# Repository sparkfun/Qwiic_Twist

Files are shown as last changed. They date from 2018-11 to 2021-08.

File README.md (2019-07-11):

SparkFun Qwiic Twist 
===========================================================

SparkFun Qwiic Twist

[*SparkFun Qwiic Twist (DEV-15083)*](https://www.sparkfun.com/products/15083)

Sometimes you just need a volume knob. The Qwiic Twist is a digital RGB encoder. What does that mean? The Twist takes care of all the various interrupts, switches, PWM'ing of LEDs and presents all those features over an easy-to-use I<sup>2</sup>C interface. The Qwiic Twist was designed to get rid of the large mass of wires that are needed to implement an RGB encoder in a breadboard. Stop messing around with interrupt debugging and get back to your project!

One rotation in the clockwise direction increases the overall count by 24 and -24 in the counter clockwise direction. The number of 'ticks' or steps the user has turned the knob are transmitted over I2C. Additionally, the red, green, and blue LEDs are all set via software commands and can be digitally mixed to achieve over 16 million colors. 

We designed Qwiic Twist with an indent encoder which gives the user a great 'clicky' feel. Additionally, the encoder has a built in button so the user can select an GUI menu or element by pressing on the encoder.

The I2C address of Qwiic Twist is software configurable which means you can hookup over 100 on a single I2C bus!

Repository Contents
-------------------

* **/Documents** - Datasheet for the Qwiic Twist 
* **/Firmware/Qwiic_Twist** - Firmware for the Qwiic Twist
* **Hardware** - .brd and .sch for Qwiic Twist 

Documentation
--------------
* **[Qwiic Twist Hookup Guide](https://learn.sparkfun.com/tutorials/qwiic-twist-hookup-guide)** - Hookup guide for the Qwiic Twist
* **[Qwiic Twist Arduino Library](https://github.com/sparkfun/SparkFun_Qwiic_Twist_Arduino_Library)** - Arduino Library for the Qwiic Twist
* **[Installing an Arduino Library Guide](https://learn.sparkfun.com/tutorials/installing-an-arduino-library)** - Basic information on how to install an Arduino library.
* **[Product Repository](https://github.com/sparkfun/Qwiic_Twist)** - Main repository (including hardware files)

License Information
-------------------

This product is _**open source**_! 

Please review the LICENSE.md file for license information. 

If you have any questions or concerns on licensing, please visit the [SparkFun Forum](https://forum.sparkfun.com/index.php) and post a topic. For more general questions related to our qwiic system, please visit this section of the forum: [SparkFun Forums: QWIIC SYSTEMS](https://forum.sparkfun.com/viewforum.php?f=105)

Please use, reuse, and modify these files as you see fit. Please maintain attribution to SparkFun Electronics and release any derivative under the same license.

Distributed as-is; no warranty is given.
- Your friends at SparkFun.

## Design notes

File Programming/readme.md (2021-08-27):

Programming ATtiny84x in Circuit
===========================================================

The Qwiic Twist uses an ATtiny84A that must be programmed with firmware. This is done with spring pins aka Pogo Pins and an AVR programmer of your choice. We've had success with using an [Arduino as the ISP programmer](https://www.arduino.cc/en/Tutorial/BuiltInExamples/ArduinoISP) but we use the [Tiny AVR Programmer](https://www.sparkfun.com/products/11801) for day to day work.

1) Get the Tiny AVR Programmer and the [necessary drivers](https://learn.sparkfun.com/tutorials/tiny-avr-programmer-hookup-guide#driver-installation) installed. 
2) Clear the VCC solder jumper from the Tiny AVR Programmer. This jumper is closed by default and will power the target at 5V. While 5V will not harm the ATtiny targets, but many Qwiic boards have 3.3V sensitive sensors and peripherals so it's best to power the target through a Qwiic cable.
3) Solder 6-pin [female header](https://www.sparkfun.com/products/115) to the bottom of the programmer
4) Assemble the [SparkFun ISP Pogo Adapter](https://www.sparkfun.com/products/11591)
5) Attach the pogo adapter to the bottom of the programmer.

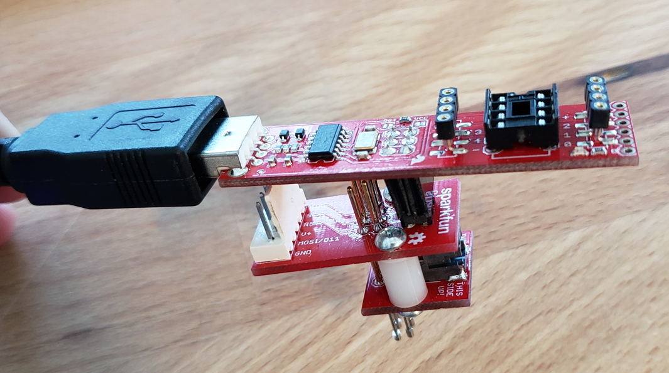
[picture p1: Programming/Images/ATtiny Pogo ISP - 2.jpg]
Programming ISP via Pogo Pins on ATtiny84A


6) Identify and mark pin 1 on the bottom of the adapter. You'll need to know where pin 1 is to align it on the target ISP holes.

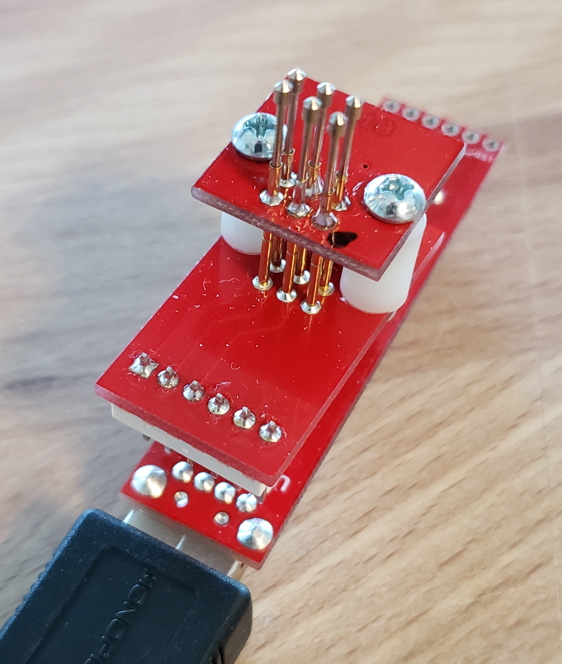
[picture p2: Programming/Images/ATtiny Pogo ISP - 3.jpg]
Programming ISP via Pogo Pins on ATtiny84A


7) Attach Tiny AVR Programmer to a USB extension cable to allow free movement of the programmer. Confirm that avrdude can see the programmer.
8) Connect the target device to a development board using a Qwiic cable so that it is powered.
9) Download the contents of the 'Programming' folder so that you have **avrdude.exe**, **avrdude.conf**, and **program_qwiic_twist.bat** in a folder.
9) Open a command line, navigate to 'program_qwiic_twist.bat' and run. It should fail because no ATtiny was detected. If it failed because an attinyusb was not found then you may need to troubleshoot your Tiny AVR Programmer and/or edit the batch file to match your programmer type.
10) Press and hold the pogo pins against the 6 exposed pins on the target. Your mark on the pogo pins should match with the small white silkscreen on the ISP on the target. You may need to wiggle the Pogo adapter until you hear all 6 pins seat into the ISP footprint.

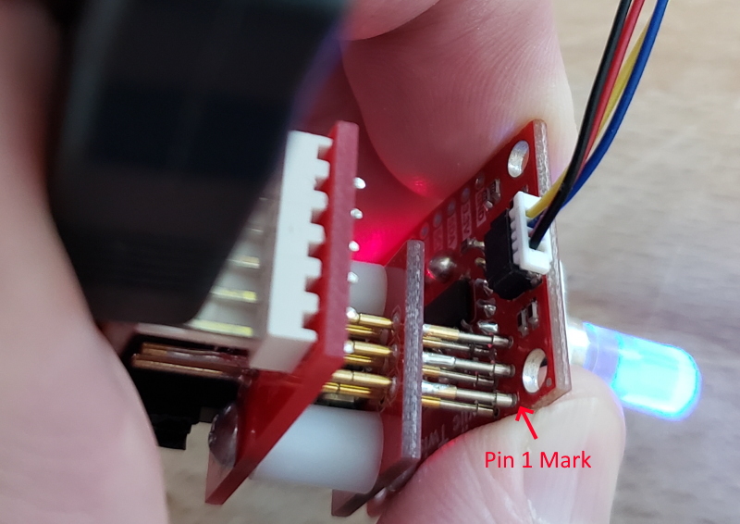
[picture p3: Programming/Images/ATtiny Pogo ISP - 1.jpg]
Programming ISP via Pogo Pins on ATtiny84A


11) Press enter with your free hand to begin programming.
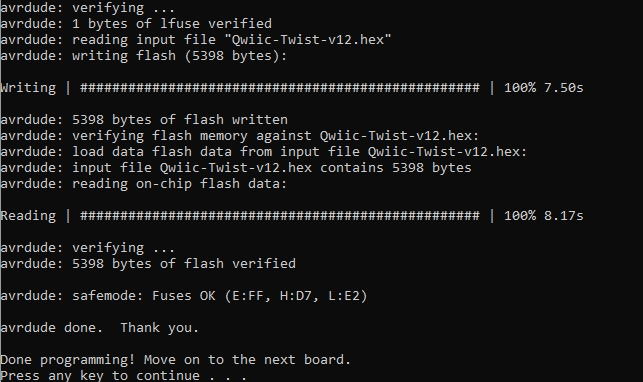
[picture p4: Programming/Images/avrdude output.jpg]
Programming ISP via Pogo Pins on ATtiny84A


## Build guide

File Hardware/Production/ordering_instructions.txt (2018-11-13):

panel size, 76x195mm
PCB thickness, 1.6mm
number of layers, 2
soldermask color, Red
silkscreen color, White
oz copper, 1oz
finish, HASL lead free
stencils, top+bottom
pcs per panel, 14

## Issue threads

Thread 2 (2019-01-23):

Change INT to a state machine

nseidle, 2019-01-23:
The interrupt pin toggles in bad ways.

When a user reads any bytes from Twist it causes the INT pin to go to high impedance, indicating the clearing of interrupts. However, back in the main loop the interrupt bits are still set so the INT pin is then set back to low. This looks like a toggle INT pin to the user.

Better to go to a state machine such as the one used on Qwiic MP3 Trigger.

nseidle, 2019-07-01:
Fixed in v1.2 of firmware now pushed to production.

Closed 2019-07-01.

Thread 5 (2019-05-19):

Schematic has wrong I2C address listed

EmbeddedMan, 2019-05-19:
The current version of the Eagle Schematic for this product lists it's I2C address as 0x5B (default). However, it does not respond to 0x5B out of the box.

Instead, if you look at the 'register map' here : https://cdn.sparkfun.com/r/600-600/assets/5/3/d/5/6/RegisterMap.jpg (linked to from the SparkFun product page for this product) it says the I2C address is 0x3F, which the board does respond to out of the box. (And the line in the firmware const byte I2C_ADDRESS_DEFAULT = 0x3F; also reflects this address.)

Either the schematic should be updated to reflect the firmware and register map, or the register map and firmware should be updated to reflect the schematic.

nseidle, 2019-05-20:
Sorry! My fault. Schematic text was pulled in from previous product. SCH on repo has been fixed. PDF on product page has been fixed.

Default I2C is 0x3F. With I2C command the address can be set to any legal address. Closing jumper forces address to 0x3E regardless of what user may have set it to via software.

Closed 2019-05-20.

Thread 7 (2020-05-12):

Two Qwicc Twists bricked through normal library calls (?)

davexre, 2020-05-12:
I'm working through the Arduino library code and the firmware code to see if I can trace this down, but it seemed like a good time to open an issue for some help.

I have two Twists that have both bricked in the same way. I have a RedBoard Artemis, and an LCD-14074 that's also connected via the Qwiic bus.

I consulted SF technical support via a forum thread after the first one had issues, and they replaced the Twist (thread is here: https://forum.sparkfun.com/viewtopic.php?f=105&t=52831). Without really thinking it through, I put the replacement into my project and just ran my code on it without trying an example first to confirm function. The new Twist bricked in exactly the same was the first.

The symptoms of the bricking are that the Twist powers on with the LEDs in the last color state the Twist had before it seems to have failed (which is 0,255,0 - so, solid green), and nothing else happens. The encoder doesn't update when twisted, nor do I get a click or press state out of it. If I run an I2C scanner with just the Twist connected, the scanner finds a device at every address. I double checked the I2C scanner and bus by running it with no devices on the bus (scanner correctly reports 0 devices), and with the LCD on the bus (correctly reports a device at 0x72).

I tried a new Qwiic cable to the Twist with no luck. I also shorted the RST pin to ground for 10 seconds or so (causes the RGB LED to turn off), with no luck, either. I tried the reset pin a couple different ways (shorted upon power on, shorted while power was already applied, shorted with power supplied then remove power before removing the short) - I don't know if there's a specific order of operations there to properly reset the ATtiny84 chip?

I am using the Qwiic Twist Arduino library - and this could possibly belong as an issue there, rather than in firmware, but firmware seemed to be a reasonable place to start? It seems doubtful that this is two broken boards, but rather something that software/firmware induced? I don't currently have the means to tap into the ISP test points to reflash one of these, but would be willing to give it a whirl to see if I can bring it back to life, if I can find a way to (non-destructively) get it done.

My code is here: https://github.com/davexre/Annealer-Control - it's an absolute mess, at the moment, but this is the code that causes the issue. The basic interactions with the I2C bus that shake this out look like:

```
#define GREEN     0,255,0
TWIST twist;
SerLCD lcd;
boolean twistMoved = false;
boolean twistClicked = false;

setup () {
  twist.begin(Wire); // this does Wire.begin()
  lcd.begin(Wire);
  Wire.setClock(400000);

  // some stuff happens in between

  twist.clearInterrupts();
  (void) twist.getDiff(true);
  twist.setCount(0);
  twist.setColor(GREEN);

  lcd.clear();
  updateLCD(true); // prints a bunch of stuff to the LCD
}

// it seems likely that we're dead here, but the loop is running before
// any action can be taken, so it could be this code, too...

loop () {

  if ( twist.isClicked() ) {
    twistPressed = true;
  }
  // potentially do something based on that

  twistMoved = twist.isMoved();

  // this should be true at the point I see the failure
  if (twistMoved && annealState == WAIT_BUTTON) {
    twistDiff = twist.getDiff(true);

    // plus some other stuff unrelated to I2C bus

    int twistCount = twist.getCount();
    if ((twistCount > 32000) || (twistCount < -32000)) {
      twist.setCount(0); // prevent over/underflow
    }
    twistMoved = false;
  }
    else if (twistMoved) {  // and we're somewhere else in the state machine
    twistDiff = twist.getDiff(); // clear the difference
    twistMoved = false;
  }

  // then we enter the state machine, where we periodically update the
  // LCD via the updateLCD() function, which calls SerLCD's setCursor(),
  // print(), and clear() methods.

}

```
We never get to a point where which switch to a different state in the state machine, but the remaining code may change the LED color on the Twist.

nseidle, 2020-05-12:
First - I am sorry for the frustration! This is no good at all.

Second - If you're interested, I can provide you with a [pogo based](https://www.sparkfun.com/products/11591) [pocket programmer](https://www.sparkfun.com/products/11801) that we use for programming. It should recover any unit you've got. You'll need to install Konde's [ATtiny core](https://github.com/SpenceKonde/ATTinyCore). But then you'll be able to program this device (and any of our Qwiic ATtiny products).

Third - I am perplexed. But I will think on the matter and try to replicate. I am terribly behind but I'll try to get to it this week.

davexre, 2020-05-12:
A programmer would help a lot! If I can bring one back to life, I can beat it up again, and maybe get down to the bottom of what's going on. This makes me wish I had access to a protocol analyzer, too! I'll drop you my contact/mailing info separately via email?

I didn't expect to run into this sort of issue, but it's an opportunity to learn. Either I'm doing something really dumb, or I stumbled into a corner case - or I somehow got two bad pieces of hardware (which seems unlikely). Either way, I can learn something out of it. But, before I go tearing through a bunch of code on a wild goose chase, it seemed like a good point to raise a flag!

nseidle, 2020-05-13:
Got one built for you. Should ship this week.

davexre, 2020-05-13:
Awesome - thank you! Once I have one back to life, I'll work on cutting the test case down to something more succinct than my current body of code!

davexre, 2020-05-18:
Received the programmer today, and successfully flashed my 1st Twist using it (according to verbose output from the upload). Thanks again for sending that over!

I set the Arduino IDE to clear the EEPROM, which appears to have been successful - the colored LEDs are now solid white, instead of the green value that was previously stored in the EEPROM. That might also suggest that the firmware is running correctly on the Twist and doing some things right (it's read 0xFF from all three LED register locations in the EEPROM, anyway).

Unfortunately, the Twist is still answering on every I2C address, and so still doesn't work - even loading Twist Example1. To double check, I disconnected the Qwiic cable from the Twist and ran the i2C scanner again - it found no devices.

I still have my second Twist in the state it was left in after initially failing - I haven't reflashed that one, yet. Any thoughts on what next steps might be, here?

davexre, 2020-05-19:
After letting it sit for the night, some sanity checking seemed wise.

I loaded and ran a couple of examples on the reflashed Twist this morning. I can successfully run Blink (with LEDBUILTIN changed to one of the LED pins on the encoder), and the Button example (also with the pins altered appropriately).

Reflashed with the Twist firmware, and attached it to the RedBoard Artemis via Qwiic cable. The I2C scanner still reports the Twist answering at every address. I should add that I'm running Nick Gammon's I2C scanner - date on the code is 20th April, 2011, in case that's somehow important.

I tried a couple of other previously unused Qwiic cables, just to reverify it wasn't that, with no change. I checked that the RedBoard Artemis was actually supplying 3.3V on the Qwiic connector, and it is.

I also verified that the pullup resistors on SDA and SCL on the Twist are connected and are the correct resistors, and they are.

For a moment, I wondered if the board had been electrically damaged (like, maybe the LCD is misbehaving in a way to that bugs the Twists, but not the RedBoard Artemis), but there doesn't seem to be a way to damage the I2C communication pathways on the board or the associated pins on the ATtiny84 without also preventing me from reflashing the board.

However, the problem persists past successful reflashing of the ATtiny84 and erasing of the EEPROM. This no longer seems like a firmware problem, but at the moment, I'm lost as to what the problem might be. I think I've checked over everything that I can, and verified that all of those things are as they should be.

Unfortunately, I don't have access to a protocol analyzer, so I can't capture a trace of the bus activity and see if that yields any clues.

If it would help, I'd be happy to send you the 2nd Twist (the one that's still in the initial failure state) - I only paid for one, and since they both have the problem, I'm no better off with the 2nd one in hand?

davexre, 2020-05-27:
One more data point. TL;DR - it looks like both Twists are partially working, but for reasons unknown are only able to receive communications from the controller board, and not respond. Additionally, some difference between a regular ATmega328 board and the RedBoard Artemis causes it to appear that the Twists are answering at all 112 available I2C addresses on the Artemis, but not on the RedBoard.

For non-related reasons, I ordered a SparkFun RedBoard and Qwiic Shield. I decided to hook up one of the Twists to see if there was a difference, and was surprised that I found one.

On the ATmega328 based board, the Twist boards both answer to a single I2C address (you will recall from above that they answer at 112 addresses when attached to my RedBoard Artemis) - the reflashed board answers at 0x3E (the Addr jumper is soldered on that one), and the 2nd Twist answers at 0x3F.

However, neither Twist seems to respond to commands correctly. I ran several example sketches on the 2nd board

Example11_GetVersion responds with "The current firmware version is: 0.0".

Example2_SetColor is actually able to change the color on the knob! But, the encoder doesn't return a count (count always reported as 0).

Example3_CrazyColor changes the knob colors correctly, but the encoder doesn't return a count (count always reported as 0).

Example4_ConnectColor - the colors correctly change on the knob when I turn it. Again, no count is returned when the knob is turned (count always reported as 0). This suggests that the encoder knob is still functioning correctly, and the ATtiny84 is catching interrupts from it appropriately and setting the knob color.

Example7_SetCount - Count and Difference always reported as 0. (not 1000, as you might expect, if it was the encoder knob that was dysfunctional)

Based on that - it appears that the Twists are somehow able to receive communication from the RedBoard but are somehow incapable of responding. Some difference in the Wire libraries or hardware between the RedBoard and the RedBoard Artemis is probably responsible for the Twists seeming to answer at all 112 I2C addresses on the Artemis, but not the regular RedBoard. This may or may not be a bug for the Apollo3 core.

I've had to move on to a regular encoder for my original project, but these problems seem 100% reproducible. I'm happy to perform additional tests, etc. If I get to a point where I can dig deeper, I certainly will.

nseidle, 2020-05-27:
Sorry, I can't seem to replicate. What is the contents of your updateLCD function?

My code:

    #include <Wire.h>

    #include <SerLCD.h> //Click here to get the library: http://librarymanager/All#SparkFun_SerLCD
    SerLCD lcd; // Initialize the library with default I2C address 0x72

    #include "SparkFun_Qwiic_Twist_Arduino_Library.h" //Click here to get the library: http://librarymanager/All#SparkFun_Twist
    TWIST twist; //Create instance of this object

    #define GREEN     0,255,0
    bool twistPressed = false;
    bool twistMoved = false;
    int twistDiff = 0;

    void setup()
    {
    Serial.begin(115200);
    Serial.println("Debug issue https://github.com/sparkfun/Qwiic_Twist/issues/7");

    Wire.begin();
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

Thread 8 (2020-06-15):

Steps for Flashing Updated Firmware

robfrawley, 2020-06-15:
Are there any resources that detail the programming process for this board. I bought a Twist only two months ago from Sparkfun and it appears to only have the v1.0 firmware (which, importantly for my usage, is lacking the "limiting" functionality. I have no experience with ATtiny whatsoever. I have been unable to find a detailed resource as to programming the Twist with the latest firmware, and do not think I have the proper hardware, either (I am also slightly annoyed that it appears I need to spend $15 buying an ATR Programmer for a product that should have shipped with the updated firmware, to begin with). Any thoughts? Thanks!

robfrawley, 2020-06-16:
Further details and additional possible discussion can be found on the SparkFun forums at https://forum.sparkfun.com/viewtopic.php?f=105&t=53179.

nseidle, 2020-06-17:
Hi Rob - sorry for the frustrating experience. We don't currently have a good document on upgrading the Twist.

Did you run the [Ex11](https://github.com/sparkfun/SparkFun_Qwiic_Twist_Arduino_Library/blob/master/examples/Example11_GetVersion/Example11_GetVersion.ino) to verify the version number? We've been on v1.2 for over a year now. It's not impossible that you got v1.0 but definitely head scratching.

robfrawley, 2020-06-17:
@nseidle The way I discovered that my Quiic Twist was running `v1.0` firmware (and realized the "limit" functionality was not available due to this) was actually by running [Example 12 (Set Limit)](https://github.com/sparkfun/SparkFun_Qwiic_Twist_Arduino_Library/blob/master/examples/Example12_SetLimit/Example12_SetLimit.ino), which itself calls the `getVersion()` library function; it performs a version check to confirm API compatibility before querying the `setLimit()` and `getLimit()` API endpoints:
```
int currentVersion = twist.getVersion();
if (currentVersion < 0x0201) { //v1.2 in two byte form
  Serial.print("The current firmware version is: ");
  Serial.print(currentVersion & 0xFF);
  Serial.print(".");
  Serial.println(currentVersion >> 8);
  Serial.println("This feature is not supported. Please consider upgrading the firmware on your Qwiic Twist. Freezing.");
  while (1); //Freeze
}
```
I thought nothing of the version check conditional from `Example 12` when I pasted it into my PlatformIO IDE and clicked "upload", I was only trying to determine how I was misusing the `(get|set)Limit`API endpoints (as they were not working in my own code), but to my surprise, the console monitor for `Example 12` output that I was on firmware `v1.0`, provided the "unsupported feature" warning, and subsequently froze.

I don't suspect this is a regular issue either; I've ordered countless components from SparkFun over the years and this is the first instance where I've received a product with such an out-of-date firmware. Hopefully, you guys can provide some guidance on how I should proceed. Thanks for the timely response! All the best.

robfrawley, 2020-07-03:
@nseidle Any thoughts?

JimmyBlunt, 2020-11-09:
Is there any progress on that issue.
Just the steps with a short description  how to get the firmware updated would be really handy.
I'm struggling too and just can't find any helpful documents that describe this in detail.
T

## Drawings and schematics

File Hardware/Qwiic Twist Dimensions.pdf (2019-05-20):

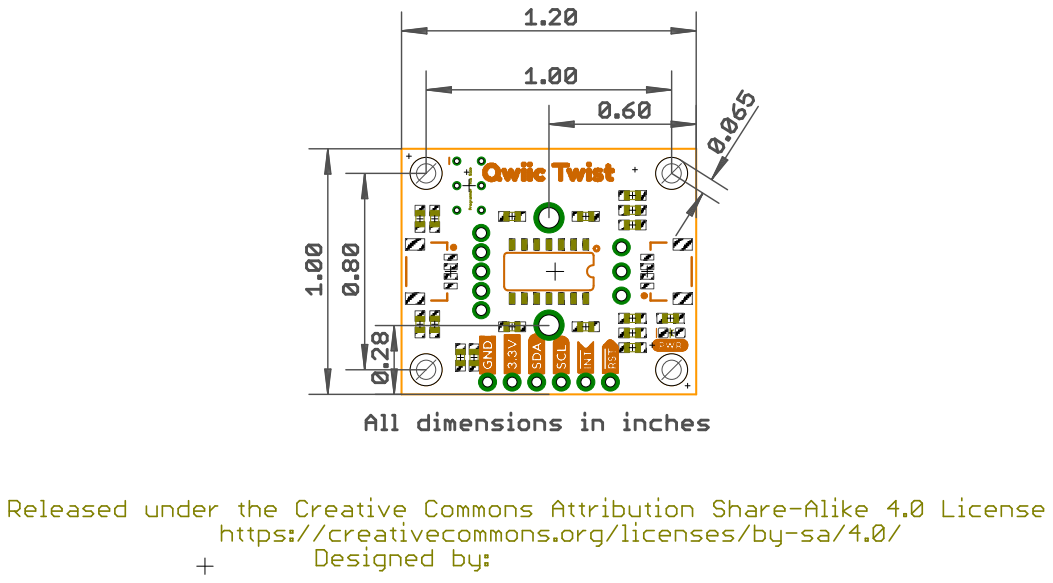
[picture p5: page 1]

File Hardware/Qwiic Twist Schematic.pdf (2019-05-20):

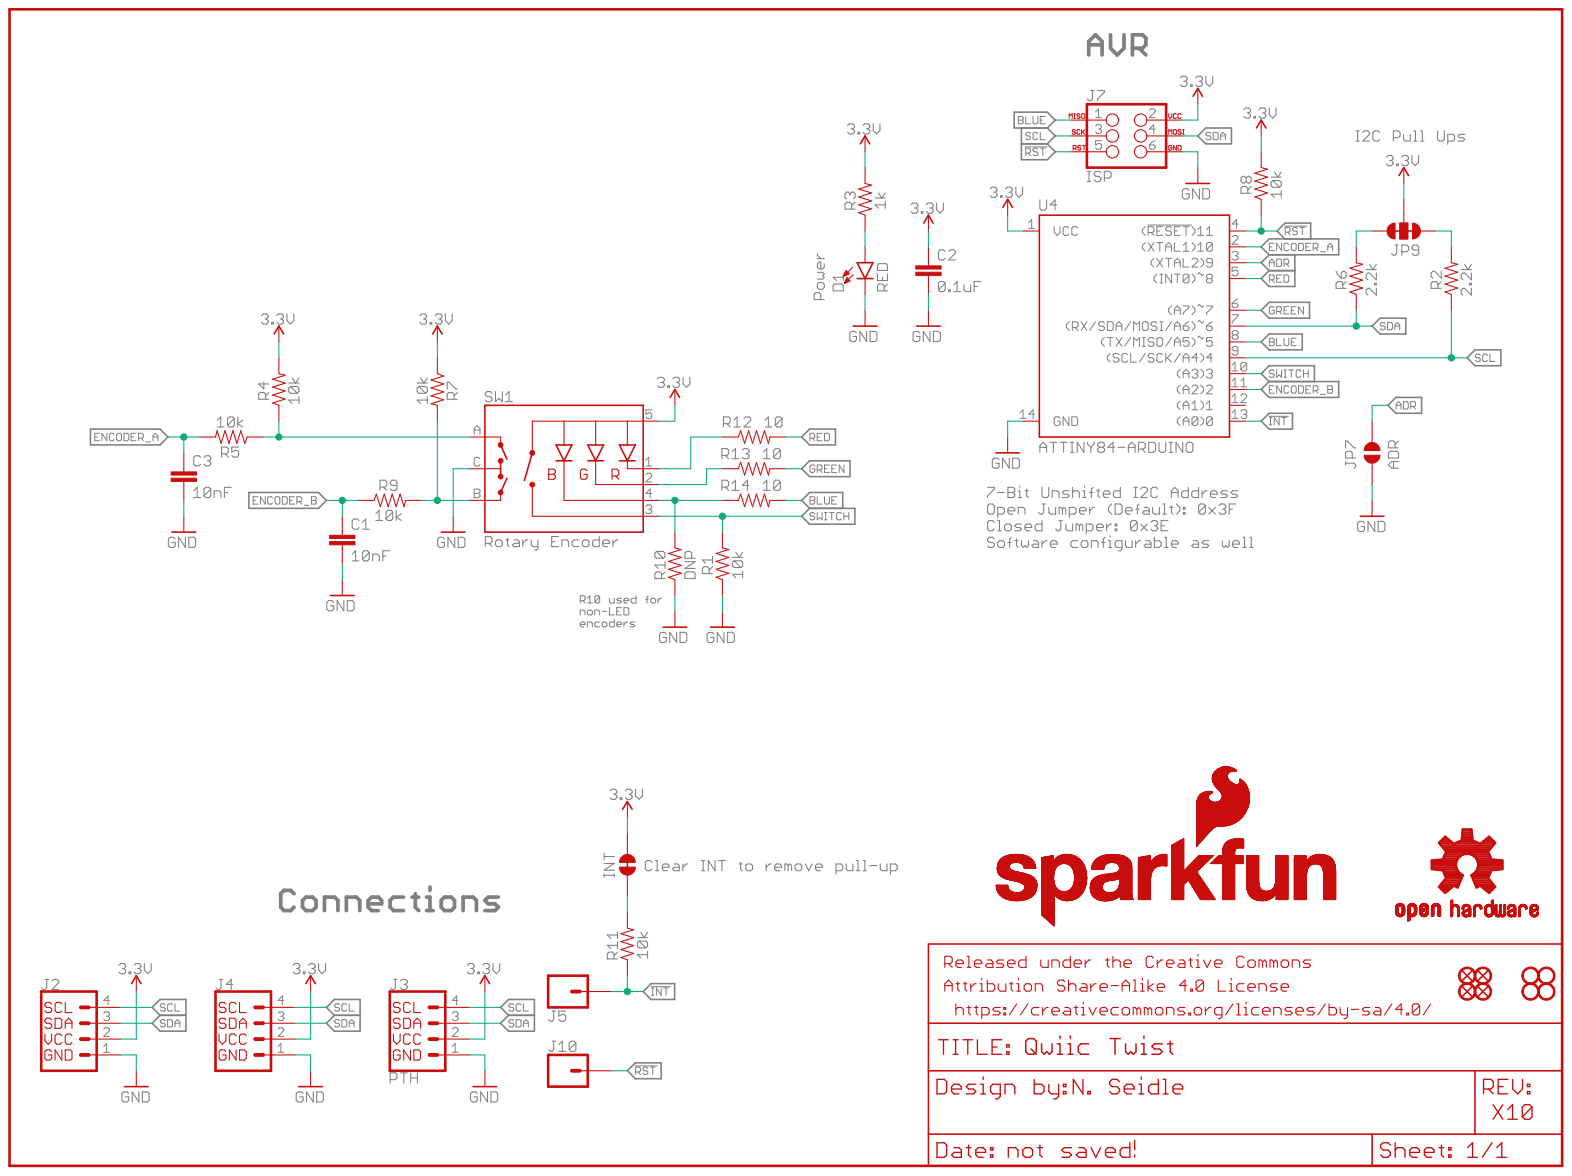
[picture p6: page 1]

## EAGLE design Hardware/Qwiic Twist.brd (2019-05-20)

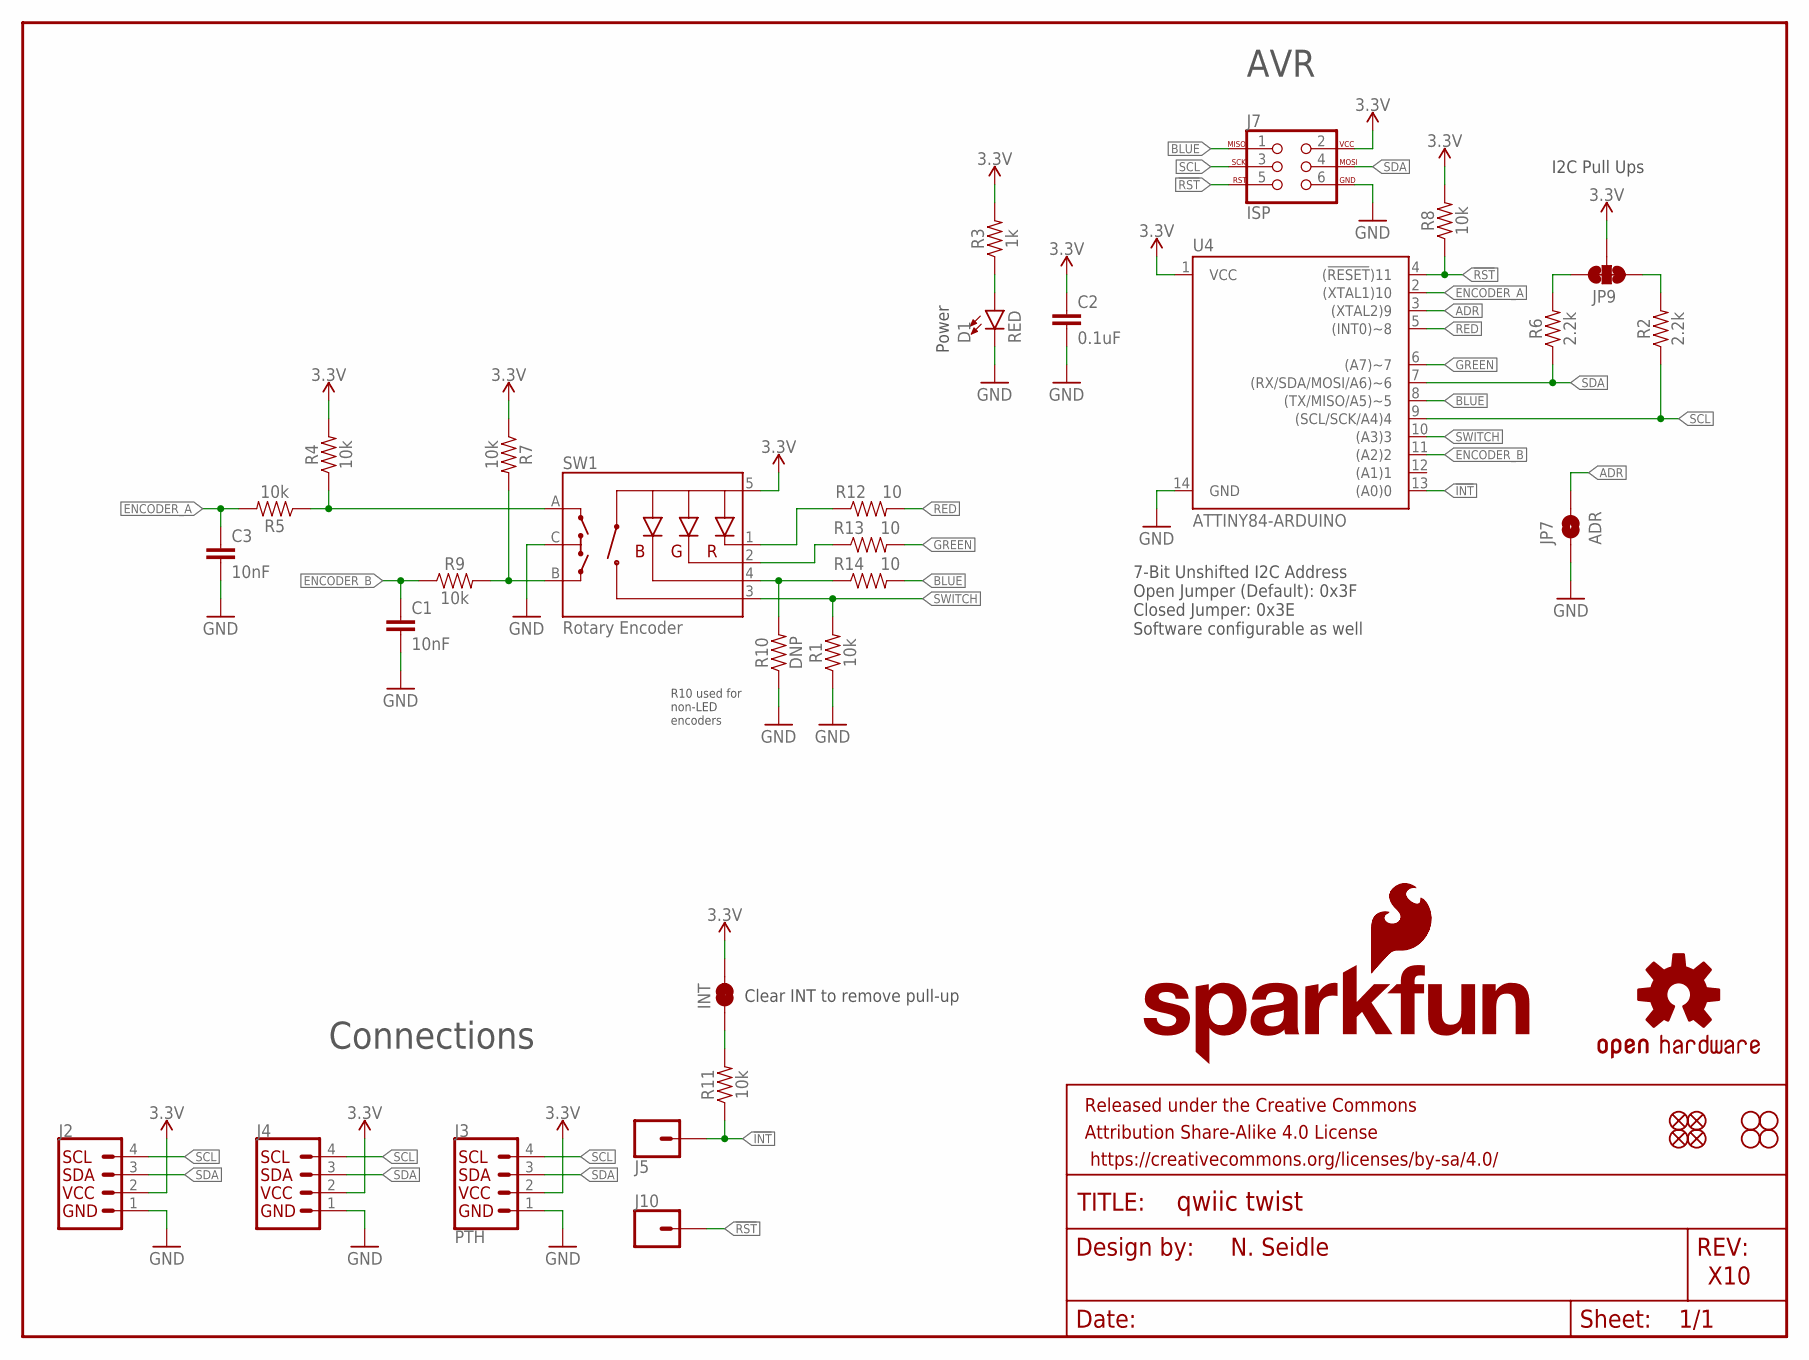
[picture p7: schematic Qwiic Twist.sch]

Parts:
C1, C3: 10nF; 0603
C2: 0.1uF; 0603
D1: RED; LED-0603
FRAME1: FRAME-LETTER; CREATIVE_COMMONS
INT: JUMPER-SMT_2_NC_TRACE_SILK; SMT-JUMPER_2_NC_TRACE_SILK
J2, J4: QWIIC_CONNECTORJS-1MM; 1X04_1MM_RA
J3: PTH; 1X04_NO_SILK
J5, J10: CONN_01PTH_NO_SILK_YES_STOP; 1X01_NO_SILK
J7: ISP; 2X3_TEST_POINTS
JP1, JP2, JP5, JP6: FIDUCIALUFIDUCIAL; MICRO-FIDUCIAL
JP3, JP4, JP11, JP13: STAND-OFF
JP7: ADR; SMT-JUMPER_2_NO_SILK
JP9: JUMPER-SMT_3_2-NC_TRACE_SILK; SMT-JUMPER_3_2-NC_TRACE_SILK
LOGO1: OSHW-LOGOMINI; OSHW-LOGO-MINI
LOGO2: SFE_LOGO_NAME_FLAME.1_INCH; SFE_LOGO_NAME_FLAME_.1
LOGO3: SFE_LOGO_FLAME.1EXP; SFE_LOGO_FLAME_COPPER_EXPOSED_.1
R1, R4, R5, R7, R8, R9, R11: 10k; 0603
R2, R6: 2.2k; 0603
R3: 1k; 0603
R10: DNP; 0603
R12, R13, R14: 10; 0603
SW1: Rotary Encoder; ENCODER_LED_3_KIT
U4: ATTINY84-ARDUINO; SO14

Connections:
3.3V: C2.1, INT.2, J2.2, J3.2 (VCC), J4.2, J7.2, JP9.2, R3.2, R4.2, R7.1, R8.2, SW1.5 (+), U4.1 (VCC)
!INT: J5.1, R11.1, U4.13 ((A0)0)
!RST: J7.5, J10.1, R8.1, U4.4 ((!RESET!)11)
A: R4.1, R5.1, SW1.A
ADR: JP7.2, U4.3 ((XTAL2)9)
B: R7.2, R9.2, SW1.B
BLUE: J7.1, R14.2, U4.8 ((TX/MISO/A5)~5)
BLUE_RAW: R10.2, R14.1, SW1.4 (-B)
ENCODER_A: C3.1, R5.2, U4.2 ((XTAL1)10)
ENCODER_B: C1.1, R9.1, U4.11 ((A2)2)
GND: C1.2, C2.2, C3.2, D1.C, J2.1, J3.1 (GND), J4.1, J7.6, JP7.1, R1.1, R10.1, SW1.C, U4.14 (GND)
GREEN: R13.2, U4.6 ((A7)~7)
GREEN_RAW: R13.1, SW1.2 (-G)
INT_R: INT.1, R11.2
unnamed: D1.A, R3.1
RED: R12.2, U4.5 ((INT0)~8)
RED_RAW: R12.1, SW1.1 (-R)
SCL: J2.4, J3.4 (SCL), J4.4, J7.3, R2.1, U4.9 ((SCL/SCK/A4)4)
SCL_PU1: JP9.1, R2.2
SDA: J2.3, J3.3 (SDA), J4.3, J7.4, R6.1, U4.7 ((RX/SDA/MOSI/A6)~6)
SDA_PU1: JP9.3, R6.2
SWITCH: R1.2, SW1.3 (SW), U4.10 ((A3)3)

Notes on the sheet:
N. Seidle
X10
7-Bit Unshifted I2C Address Open Jumper (Default): 0x3F Closed Jumper: 0x3E Software configurable as well
I2C Pull Ups
AVR
Connections
Power
R10 used for non-LED encoders
Clear INT to remove pull-up

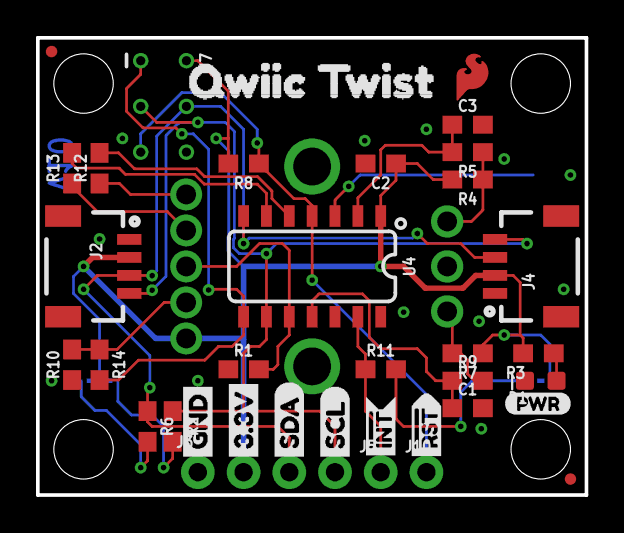
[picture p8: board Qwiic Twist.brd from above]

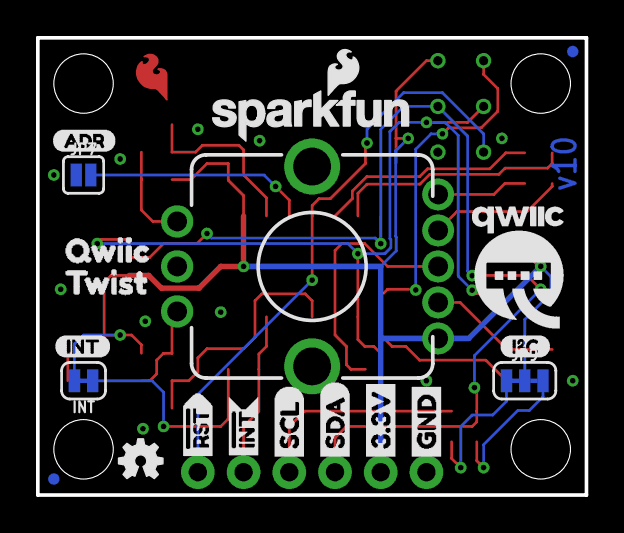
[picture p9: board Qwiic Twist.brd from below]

Board: 2 copper layers, 30.5 x 25.4 mm, 61 parts (20 on the bottom side), 22 nets.

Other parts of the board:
U$1: QWIIC1
U$2: INT0
U$3, U$22: GND1
U$4, U$21: 3#3V2
U$5, U$27: SDA8
U$6, U$26: SCL9
U$7, U$16: RST#-[>
U$8: I_SUPER2_C-()-03
U$9, U$11: INT#-[<
U$12: TWIST2
U$14: QWIIC_TWIST1
U$17: PWR-()-03
U$18: ADR-()-03
U$47: QWIIC-LOGO-MEDIUM

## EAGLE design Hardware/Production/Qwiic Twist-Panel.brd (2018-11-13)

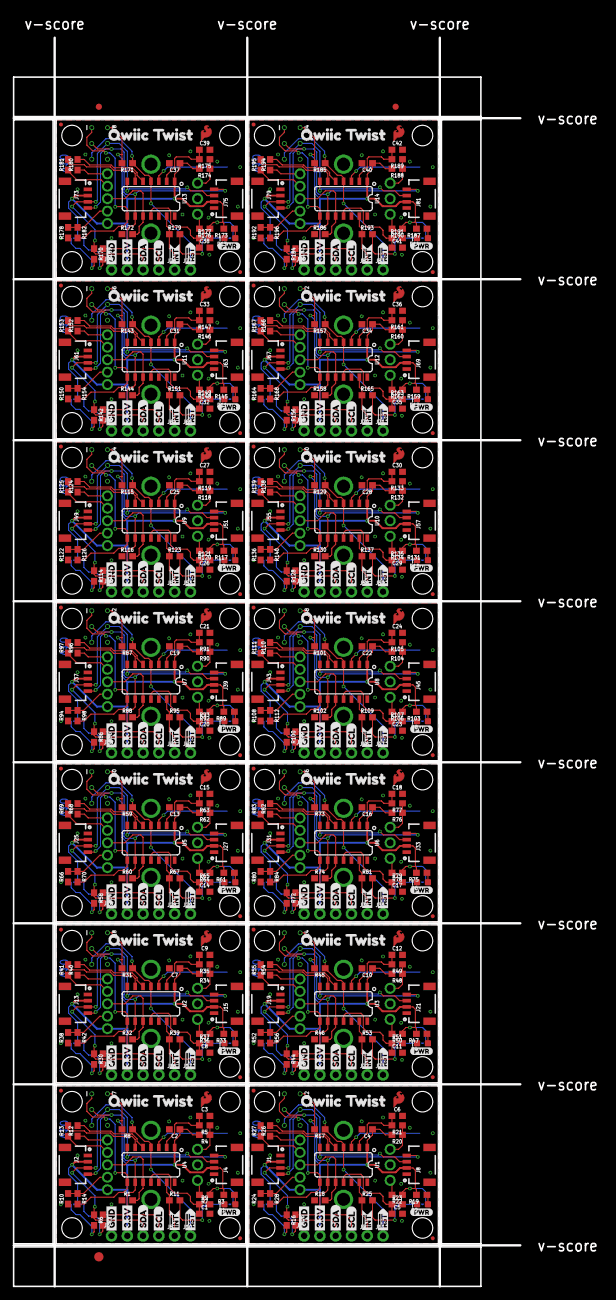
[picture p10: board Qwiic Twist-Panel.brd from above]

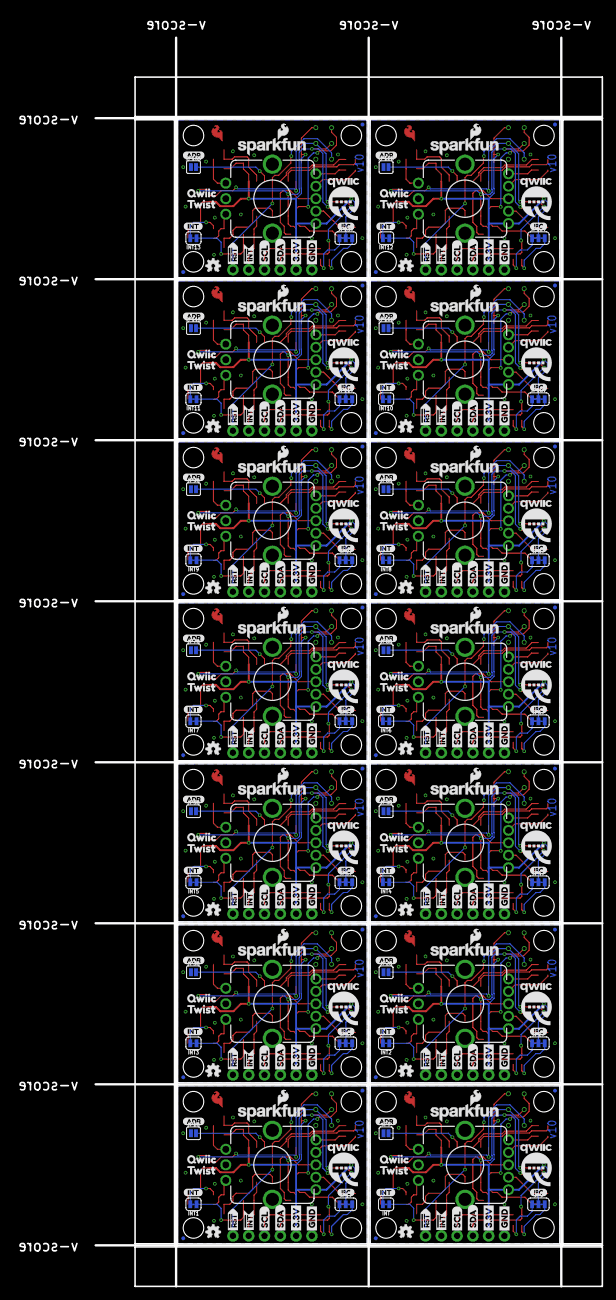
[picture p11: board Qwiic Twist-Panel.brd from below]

Board: 2 copper layers, 81.5 x 200.9 mm, 843 parts (280 on the bottom side), 308 nets.

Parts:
C1, C3, C5, C6, C8, C9, C11, C12, C14, C15, C17, C18, C20, C21, C23, C24, C26, C27, C29, C30, C32, C33, C35, C36, C38, C39, C41, C42: 10nF; 0603
C2, C4, C7, C10, C13, C16, C19, C22, C25, C28, C31, C34, C37, C40: 0.1uF; 0603
D1, D2, D3, D4, D5, D6, D7, D8, D9, D10, D11, D12, D13, D14: RED; LED-0603
E$1, E$2: FIDUCIAL-1X2
E$3: FIDUCIAL-1.5X3
INT, INT1, INT2, INT3, INT4, INT5, INT6, INT7, INT8, INT9, INT10, INT11, INT12, INT13: SMT-JUMPER_2_NC_TRACE_SILK
J1, J2, J4, J8, J13, J15, J19, J21, J25, J27, J31, J33, J37, J39, J43, J45, J49, J51, J55, J57, J61, J63, J67, J69, J73, J75, J79, J81: 1X04_1MM_RA
J3, J6, J14, J20, J26, J32, J38, J44, J50, J56, J62, J68, J74, J80: PTH; 1X04_NO_SILK
J5, J9, J10, J11, J16, J17, J22, J23, J28, J29, J34, J35, J40, J41, J46, J47, J52, J53, J58, J59, J64, J65, J70, J71, J76, J77, J82, J83: 1X01_NO_SILK
J7, J12, J18, J24, J30, J36, J42, J48, J54, J60, J66, J72, J78, J84: ISP; 2X3_TEST_POINTS
JP1, JP2, JP5, JP6, JP12, JP14, JP15, JP20, JP23, JP24, JP25, JP30, JP33, JP34, JP35, JP40, JP43, JP44, JP45, JP50, JP53, JP54, JP55, JP60, JP63, JP64, JP65, JP70, JP73, JP74, JP75, JP80, JP83, JP84, JP85, JP90, JP93, JP94, JP95, JP100, JP103, JP104, JP105, JP110, JP113, JP114, JP115, JP120, JP123, JP124, JP125, JP130, JP133, JP134, JP135, JP140: FIDUCIALUFIDUCIAL; MICRO-FIDUCIAL
JP3, JP4, JP8, JP10, JP11, JP13, JP18, JP19, JP21, JP22, JP28, JP29, JP31, JP32, JP38, JP39, JP41, JP42, JP48, JP49, JP51, JP52, JP58, JP59, JP61, JP62, JP68, JP69, JP71, JP72, JP78, JP79, JP81, JP82, JP88, JP89, JP91, JP92, JP98, JP99, JP101, JP102, JP108, JP109, JP111, JP112, JP118, JP119, JP121, JP122, JP128, JP129, JP131, JP132, JP138, JP139: STAND-OFF
JP7, JP16, JP26, JP36, JP46, JP56, JP66, JP76, JP86, JP96, JP106, JP116, JP126, JP136: ADR; SMT-JUMPER_2_NO_SILK
JP9, JP17, JP27, JP37, JP47, JP57, JP67, JP77, JP87, JP97, JP107, JP117, JP127, JP137: SMT-JUMPER_3_2-NC_TRACE_SILK
LOGO1, LOGO4, LOGO7, LOGO10, LOGO13, LOGO16, LOGO19, LOGO22, LOGO25, LOGO28, LOGO31, LOGO34, LOGO37, LOGO40: OSHW-LOGOMINI; OSHW-LOGO-MINI
LOGO2, LOGO5, LOGO8, LOGO11, LOGO14, LOGO17, LOGO20, LOGO23, LOGO26, LOGO29, LOGO32, LOGO35, LOGO38, LOGO41: SFE_LOGO_NAME_FLAME.1_INCH; SFE_LOGO_NAME_FLAME_.1
LOGO3, LOGO6, LOGO9, LOGO12, LOGO15, LOGO18, LOGO21, LOGO24, LOGO27, LOGO30, LOGO33, LOGO36, LOGO39, LOGO42: SFE_LOGO_FLAME.1EXP; SFE_LOGO_FLAME_COPPER_EXPOSED_.1
R1, R4, R5, R7, R8, R9, R11, R17, R18, R20, R21, R22, R23, R25, R31, R32, R34, R35, R36, R37, R39, R45, R46, R48, R49, R50, R51, R53, R59, R60, R62, R63, R64, R65, R67, R73, R74, R76, R77, R78, R79, R81, R87, R88, R90, R91, R92, R93, R95, R101, R102, R104, R105, R106, R107, R109, R115, R116, R118, R119, R120, R121, R123, R129, R130, R132, R133, R134, R135, R137, R143, R144, R146, R147, R148, R149, R151, R157, R158, R160, R161, R162, R163, R165, R171, R172, R174, R175, R176, R177, R179, R185, R186, R188, R189, R190, R191, R193: 10k; 0603
R2, R6, R15, R16, R29, R30, R43, R44, R57, R58, R71, R72, R85, R86, R99, R100, R113, R114, R127, R128, R141, R142, R155, R156, R169, R170, R183, R184: 2.2k; 0603
R3, R19, R33, R47, R61, R75, R89, R103, R117, R131, R145, R159, R173, R187: 1k; 0603
R10, R24, R38, R52, R66, R80, R94, R108, R122, R136, R150, R164, R178, R192: DNP; 0603
R12, R13, R14, R26, R27, R28, R40, R41, R42, R54, R55, R56, R68, R69, R70, R82, R83, R84, R96, R97, R98, R110, R111, R112, R124, R125, R126, R138, R139, R140, R152, R153, R154, R166, R167, R168, R180, R181, R182, R194, R195, R196: 10; 0603
SW1, SW2, SW3, SW4, SW5, SW6, SW7, SW8, SW9, SW10, SW11, SW12, SW13, SW14: Rotary Encoder; ENCODER_LED_3_KIT
U1, U2, U3, U4, U5, U6, U7, U8, U9, U10, U11, U12, U13, U14: ATTINY84-ARDUINO; SO14
U$1, U$36, U$57, U$77, U$97, U$117, U$137, U$157, U$177, U$197, U$217, U$237, U$257, U$277: QWIIC1
U$2, U$39, U$60, U$80, U$100, U$120, U$140, U$160, U$180, U$200, U$220, U$240, U$260, U$280: INT0
U$3, U$13, U$20, U$22, U$41, U$44, U$62, U$65, U$82, U$85, U$102, U$105, U$122, U$125, U$142, U$145, U$162, U$165, U$182, U$185, U$202, U$205, U$222, U$225, U$242, U$245, U$262, U$265: GND1
U$4, U$10, U$21, U$23, U$40, U$45, U$61, U$66, U$81, U$86, U$101, U$106, U$121, U$126, U$141, U$146, U$161, U$166, U$181, U$186, U$201, U$206, U$221, U$226, U$241, U$246, U$261, U$266: 3#3V2
U$5, U$19, U$24, U$27, U$43, U$46, U$64, U$67, U$84, U$87, U$104, U$107, U$124, U$127, U$144, U$147, U$164, U$167, U$184, U$187, U$204, U$207, U$224, U$227, U$244, U$247, U$264, U$267: SDA8
U$6, U$15, U$25, U$26, U$42, U$48, U$63, U$68, U$83, U$88, U$103, U$108, U$123, U$128, U$143, U$148, U$163, U$168, U$183, U$188, U$203, U$208, U$223, U$228, U$243, U$248, U$263, U$268: SCL9
U$7, U$16, U$31, U$32, U$52, U$53, U$72, U$73, U$92, U$93, U$112, U$113, U$132, U$133, U$152, U$153, U$172, U$173, U$192, U$193, U$212, U$213, U$232, U$233, U$252, U$253, U$272, U$273: RST#-[>
U$8, U$28, U$49, U$69, U$89, U$109, U$129, U$149, U$169, U$189, U$209, U$229, U$249, U$269: I_SUPER2_C-()-03
U$9, U$11, U$29, U$30, U$50, U$51, U$70, U$71, U$90, U$91, U$110, U$111, U$130, U$131, U$150, U$151, U$170, U$171, U$190, U$191, U$210, U$211, U$230, U$231, U$250, U$251, U$270, U$271: INT#-[<
U$12, U$37, U$58, U$78, U$98, U$118, U$138, U$158, U$178, U$198, U$218, U$238, U$258, U$278: TWIST2
U$14, U$38, U$59, U$79, U$99, U$119, U$139, U$159, U$179, U$199, U$219, U$239, U$259, U$279: QWIIC_TWIST1
U$17, U$33, U$54, U$74, U$94, U$114, U$134, U$154, U$174, U$194, U$214, U$234, U$254, U$274: PWR-()-03
U$18, U$34, U$55, U$75, U$95, U$115, U$135, U$155, U$175, U$195, U$215, U$235, U$255, U$275: ADR-()-03
U$35, U$47, U$56, U$76, U$96, U$116, U$136, U$156, U$176, U$196, U$216, U$236, U$256, U$276: QWIIC-LOGO-MEDIUM

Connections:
3.3V: C2.1, INT.2, J2.2, J3.2, J4.2, J7.2, JP9.2, R3.2, R4.2, R7.1, R8.2, SW1.5, U4.1
3.3V1: C4.1, INT1.2, J1.2, J6.2, J8.2, J12.2, JP17.2, R17.2, R19.2, R20.2, R22.1, SW2.5, U1.1
3.3V2: C7.1, INT2.2, J13.2, J14.2, J15.2, J18.2, JP27.2, R31.2, R33.2, R34.2, R36.1, SW3.5, U2.1
3.3V3: C10.1, INT3.2, J19.2, J20.2, J21.2, J24.2, JP37.2, R45.2, R47.2, R48.2, R50.1, SW4.5, U3.1
3.3V4: C13.1, INT4.2, J25.2, J26.2, J27.2, J30.2, JP47.2, R59.2, R61.2, R62.2, R64.1, SW5.5, U5.1
3.3V5: C16.1, INT5.2, J31.2, J32.2, J33.2, J36.2, JP57.2, R73.2, R75.2, R76.2, R78.1, SW6.5, U6.1
3.3V6: C19.1, INT6.2, J37.2, J38.2, J39.2, J42.2, JP67.2, R87.2, R89.2, R90.2, R92.1, SW7.5, U7.1
3.3V7: C22.1, INT7.2, J43.2, J44.2, J45.2, J48.2, JP77.2, R101.2, R103.2, R104.2, R106.1, SW8.5, U8.1
3.3V8: C25.1, INT8.2, J49.2, J50.2, J51.2, J54.2, JP87.2, R115.2, R117.2, R118.2, R120.1, SW9.5, U9.1
3.3V9: C28.1, INT9.2, J55.2, J56.2, J57.2, J60.2, JP97.2, R129.2, R131.2, R132.2, R134.1, SW10.5, U10.1
3.3V10: C31.1, INT10.2, J61.2, J62.2, J63.2, J66.2, JP107.2, R143.2, R145.2, R146.2, R148.1, SW11.5, U11.1
3.3V11: C34.1, INT11.2, J67.2, J68.2, J69.2, J72.2, JP117.2, R157.2, R159.2, R160.2, R162.1, SW12.5, U12.1
3.3V12: C37.1, INT12.2, J73.2, J74.2, J75.2, J78.2, JP127.2, R171.2, R173.2, R174.2, R176.1, SW13.5, U13.1
3.3V13: C40.1, INT13.2, J79.2, J80.2, J81.2, J84.2, JP137.2, R185.2, R187.2, R188.2, R190.1, SW14.5, U14.1
!INT: J5.1, R11.1, U4.13
!INT1: J9.1, R25.1, U1.13
!INT2: J16.1, R39.1, U2.13
!INT3: J22.1, R53.1, U3.13
!INT4: J28.1, R67.1, U5.13
!INT5: J34.1, R81.1, U6.13
!INT6: J40.1, R95.1, U7.13
!INT7: J46.1, R109.1, U8.13
!INT8: J52.1, R123.1, U9.13
!INT9: J58.1, R137.1, U10.13
!INT10: J64.1, R151.1, U11.13
!INT11: J70.1, R165.1, U12.13
!INT12: J76.1, R179.1, U13.13
!INT13: J82.1, R193.1, U14.13
!RST: J7.5, J10.1, R8.1, U4.4
!RST1: J11.1, J12.5, R17.1, U1.4
!RST2: J17.1, J18.5, R31.1, U2.4
!RST3: J23.1, J24.5, R45.1, U3.4
!RST4: J29.1, J30.5, R59.1, U5.4
!RST5: J35.1, J36.5, R73.1, U6.4
!RST6: J41.1, J42.5, R87.1, U7.4
!RST7: J47.1, J48.5, R101.1, U8.4
!RST8: J53.1, J54.5, R115.1, U9.4
!RST9: J59.1, J60.5, R129.1, U10.4
!RST10: J65.1, J66.5, R143.1, U11.4
!RST11: J71.1, J72.5, R157.1, U12.4
!RST12: J77.1, J78.5, R171.1, U13.4
!RST13: J83.1, J84.5, R185.1, U14.4
A: R4.1, R5.1, SW1.A
A1: R20.1, R21.1, SW2.A
A2: R34.1, R35.1, SW3.A
A3: R48.1, R49.1, SW4.A
A4: R62.1, R63.1, SW5.A
A5: R76.1, R77.1, SW6.A
A6: R90.1, R91.1, SW7.A
A7: R104.1, R105.1, SW8.A
A8: R118.1, R119.1, SW9.A
A9: R132.1, R133.1, SW10.A
A10: R146.1, R147.1, SW11.A
A11: R160.1, R161.1, SW12.A
A12: R174.1, R175.1, SW13.A
A13: R188.1, R189.1, SW14.A
ADR: JP7.2, U4.3
ADR1: JP16.2, U1.3
ADR2: JP26.2, U2.3
ADR3: JP36.2, U3.3
ADR4: JP46.2, U5.3
ADR5: JP56.2, U6.3
ADR6: JP66.2, U7.3
ADR7: JP76.2, U8.3
ADR8: JP86.2, U9.3
ADR9: JP96.2, U10.3
ADR10: JP106.2, U11.3
ADR11: JP116.2, U12.3
ADR12: JP126.2, U13.3
ADR13: JP136.2, U14.3
B: R7.2, R9.2, SW1.B
B1: R22.2, R23.2, SW2.B
B2: R36.2, R37.2, SW3.B
B3: R50.2, R51.2, SW4.B
B4: R64.2, R65.2, SW5.B
B5: R78.2, R79.2, SW6.B
B6: R92.2, R93.2, SW7.B
B7: R106.2, R107.2, SW8.B
B8: R120.2, R121.2, SW9.B
B9: R134.2, R135.2, SW10.B
B10: R148.2, R149.2, SW11.B
B11: R162.2, R163.2, SW12.B
B12: R176.2, R177.2, SW13.B
B13: R190.2, R191.2, SW14.B
BLUE: J7.1, R14.2, U4.8
BLUE1: J12.1, R28.2, U1.8
BLUE2: J18.1, R42.2, U2.8
BLUE3: J24.1, R56.2, U3.8
BLUE4: J30.1, R70.2, U5.8
BLUE5: J36.1, R84.2, U6.8
BLUE6: J42.1, R98.2, U7.8
BLUE7: J48.1, R112.2, U8.8
BLUE8: J54.1, R126.2, U9.8
BLUE9: J60.1, R140.2, U10.8
BLUE10: J66.1, R154.2, U11.8
BLUE11: J72.1, R168.2, U12.8
BLUE12: J78.1, R182.2, U13.8
BLUE13: J84.1, R196.2, U14.8
BLUE_RAW: R10.2, R14.1, SW1.4
BLUE_RAW1: R24.2, R28.1, SW2.4
BLUE_RAW2: R38.2, R42.1, SW3.4
BLUE_RAW3: R52.2, R56.1, SW4.4
BLUE_RAW4: R66.2, R70.1, SW5.4
BLUE_RAW5: R80.2, R84.1, SW6.4
BLUE_RAW6: R94.2, R98.1, SW7.4
BLUE_RAW7: R108.2, R112.1, SW8.4
BLUE_RAW8: R122.2, R126.1, SW9.4
BLUE_RAW9: R136.2, R140.1, SW10.4
BLUE_RAW10: R150.2, R154.1, SW11.4
BLUE_RAW11: R164.2, R168.1, SW12.4
BLUE_RAW12: R178.2, R182.1, SW13.4
BLUE_RAW13: R192.2, R196.1, SW14.4
ENCODER_A: C3.1, R5.2, U4.2
ENCODER_A1: C6.1, R21.2, U1.2
ENCODER_A2: C9.1, R35.2, U2.2
ENCODER_A3: C12.1, R49.2, U3.2
ENCODER_A4: C15.1, R63.2, U5.2
ENCODER_A5: C18.1, R77.2, U6.2
ENCODER_A6: C21.1, R91.2, U7.2
ENCODER_A7: C24.1, R105.2, U8.2
ENCODER_A8: C27.1, R119.2, U9.2
ENCODER_A9: C30.1, R133.2, U10.2
ENCODER_A10: C33.1, R147.2, U11.2
ENCODER_A11: C36.1, R161.2, U12.2
ENCODER_A12: C39.1, R175.2, U13.2
ENCODER_A13: C42.1, R189.2, U14.2
ENCODER_B: C1.1, R9.1, U4.11
ENCODER_B1: C5.1, R23.1, U1.11
ENCODER_B2: C8.1, R37.1, U2.11
ENCODER_B3: C11.1, R51.1, U3.11
ENCODER_B4: C14.1, R65.1, U5.11
ENCODER_B5: C17.1, R79.1, U6.11
ENCODER_B6: C20.1, R93.1, U7.11
ENCODER_B7: C23.1, R107.1, U8.11
ENCODER_B8: C26.1, R121.1, U9.11
ENCODER_B9: C29.1, R135.1, U10.11
ENCODER_B10: C32.1, R149.1, U11.11
ENCODER_B11: C35.1, R163.1, U12.11
ENCODER_B12: C38.1, R177.1, U13.11
ENCODER_B13: C41.1, R191.1, U14.11
GND: C1.2, C2.2, C3.2, D1.C, J2.1, J3.1, J4.1, J7.6, JP7.1, R1.1, R10.1, SW1.C, U4.14
GND1: C4.2, C5.2, C6.2, D2.C, J1.1, J6.1, J8.1, J12.6, JP16.1, R18.1, R24.1, SW2.C, U1.14
GND2: C7.2, C8.2, C9.2, D3.C, J13.1, J14.1, J15.1, J18.6, JP26.1, R32.1, R38.1, SW3.C, U2.14
GND3: C10.2, C11.2, C12.2, D4.C, J19.1, J20.1, J21.1, J24.6, JP36.1, R46.1, R52.1, SW4.C, U3.14
GND4: C13.2, C14.2, C15.2, D5.C, J25.1, J26.1, J27.1, J30.6, JP46.1, R60.1, R66.1, SW5.C, U5.14
GND5: C16.2, C17.2, C18.2, D6.C, J31.1, J32.1, J33.1, J36.6, JP56.1, R74.1, R80.1, SW6.C, U6.14
GND6: C19.2, C20.2, C21.2, D7.C, J37.1, J38.1, J39.1, J42.6, JP66.1, R88.1, R94.1, SW7.C, U7.14
GND7: C22.2, C23.2, C24.2, D8.C, J43.1, J44.1, J45.1, J48.6, JP76.1, R102.1, R108.1, SW8.C, U8.14
GND8: C25.2, C26.2, C27.2, D9.C, J49.1, J50.1, J51.1, J54.6, JP86.1, R116.1, R122.1, SW9.C, U9.14
GND9: C28.2, C29.2, C30.2, D10.C, J55.1, J56.1, J57.1, J60.6, JP96.1, R130.1, R136.1, SW10.C, U10.14
GND10: C31.2, C32.2, C33.2, D11.C, J61.1, J62.1, J63.1, J66.6, JP106.1, R144.1, R150.1, SW11.C, U11.14
GND11: C34.2, C35.2, C36.2, D12.C, J67.1, J68.1, J69.1, J72.6, JP116.1, R158.1, R164.1, SW12.C, U12.14
GND12: C37.2, C38.2, C39.2, D13.C, J73.1, J74.1, J75.1, J78.6, JP126.1, R172.1, R178.1, SW13.C, U13.14
GND13: C40.2, C41.2, C42.2, D14.C, J79.1, J80.1, J81.1, J84.6, JP136.1, R186.1, R192.1, SW14.C, U14.14
GREEN: R13.2, U4.6
GREEN1: R27.2, U1.6
GREEN2: R41.2, U2.6
GREEN3: R55.2, U3.6
GREEN4: R69.2, U5.6
GREEN5: R83.2, U6.6
GREEN6: R97.2, U7.6
GREEN7: R111.2, U8.6
GREEN8: R125.2, U9.6
GREEN9: R139.2, U10.6
GREEN10: R153.2, U11.6
GREEN11: R167.2, U12.6
GREEN12: R181.2, U13.6
GREEN13: R195.2, U14.6
GREEN_RAW: R13.1, SW1.2
GREEN_RAW1: R27.1, SW2.2
GREEN_RAW2: R41.1, SW3.2
GREEN_RAW3: R55.1, SW4.2
GREEN_RAW4: R69.1, SW5.2
GREEN_RAW5: R83.1, SW6.2
GREEN_RAW6: R97.1, SW7.2
GREEN_RAW7: R111.1, SW8.2
GREEN_RAW8: R125.1, SW9.2
GREEN_RAW9: R139.1, SW10.2
GREEN_RAW10: R153.1, SW11.2
GREEN_RAW11: R167.1, SW12.2
GREEN_RAW12: R181.1, SW13.2
GREEN_RAW13: R195.1, SW14.2
INT_R: INT.1, R11.2
INT_R1: INT1.1, R25.2
INT_R2: INT2.1, R39.2
INT_R3: INT3.1, R53.2
INT_R4: INT4.1, R67.2
INT_R5: INT5.1, R81.2
INT_R6: INT6.1, R95.2
INT_R7: INT7.1, R109.2
INT_R8: INT8.1, R123.2
INT_R9: INT9.1, R137.2
INT_R10: INT10.1, R151.2
INT_R11: INT11.1, R165.2
INT_R12: INT12.1, R179.2
INT_R13: INT13.1, R193.2
unnamed: D2.A, R19.1
unnamed: D3.A, R33.1
unnamed: D1.A, R3.1
unnamed: D4.A, R47.1
unnamed: D5.A, R61.1
unnamed: D6.A, R75.1
unnamed: D7.A, R89.1
unnamed: D8.A, R103.1
unnamed: D9.A, R117.1
unnamed: D10.A, R131.1
unnamed: D11.A, R145.1
unnamed: D12.A, R159.1
unnamed: D13.A, R173.1
unnamed: D14.A, R187.1
RED: R12.2, U4.5
RED1: R26.2, U1.5
RED2: R40.2, U2.5
RED3: R54.2, U3.5
RED4: R68.2, U5.5
RED5: R82.2, U6.5
RED6: R96.2, U7.5
RED7: R110.2, U8.5
RED8: R124.2, U9.5
RED9: R138.2, U10.5
RED10: R152.2, U11.5
RED11: R166.2, U12.5
RED12: R180.2, U13.5
RED13: R194.2, U14.5
RED_RAW: R12.1, SW1.1
RED_RAW1: R26.1, SW2.1
RED_RAW2: R40.1, SW3.1
RED_RAW3: R54.1, SW4.1
RED_RAW4: R68.1, SW5.1
RED_RAW5: R82.1, SW6.1
RED_RAW6: R96.1, SW7.1
RED_RAW7: R110.1, SW8.1
RED_RAW8: R124.1, SW9.1
RED_RAW9: R138.1, SW10.1
RED_RAW10: R152.1, SW11.1
RED_RAW11: R166.1, SW12.1
RED_RAW12: R180.1, SW13.1
RED_RAW13: R194.1, SW14.1
SCL: J2.4, J3.4, J4.4, J7.3, R2.1, U4.9
SCL1: J1.4, J6.4, J8.4, J12.3, R15.1, U1.9
SCL2: J13.4, J14.4, J15.4, J18.3, R29.1, U2.9
SCL3: J19.4, J20.4, J21.4, J24.3, R43.1, U3.9
SCL4: J25.4, J26.4, J27.4, J30.3, R57.1, U5.9
SCL5: J31.4, J32.4, J33.4, J36.3, R71.1, U6.9
SCL6: J37.4, J38.4, J39.4, J42.3, R85.1, U7.9
SCL7: J43.4, J44.4, J45.4, J48.3, R99.1, U8.9
SCL8: J49.4, J50.4, J51.4, J54.3, R113.1, U9.9
SCL9: J55.4, J56.4, J57.4, J60.3, R127.1, U10.9
SCL10: J61.4, J62.4, J63.4, J66.3, R141.1, U11.9
SCL11: J67.4, J68.4, J69.4, J72.3, R155.1, U12.9
SCL12: J73.4, J74.4, J75.4, J78.3, R169.1, U13.9
SCL13: J79.4, J80.4, J81.4, J84.3, R183.1, U14.9
SCL_PU1: JP9.1, R2.2
SCL_PU2: JP17.1, R15.2
SCL_PU3: JP27.1, R29.2
SCL_PU4: JP37.1, R43.2
SCL_PU5: JP47.1, R57.2
SCL_PU6: JP57.1, R71.2
SCL_PU7: JP67.1, R85.2
SCL_PU8: JP77.1, R99.2
SCL_PU9: JP87.1, R113.2
SCL_PU10: JP97.1, R127.2
SCL_PU11: JP107.1, R141.2
SCL_PU12: JP117.1, R155.2
SCL_PU13: JP127.1, R169.2
SCL_PU14: JP137.1, R183.2
SDA: J2.3, J3.3, J4.3, J7.4, R6.1, U4.7
SDA1: J1.3, J6.3, J8.3, J12.4, R16.1, U1.7
SDA2: J13.3, J14.3, J15.3, J18.4, R30.1, U2.7
SDA3: J19.3, J20.3, J21.3, J24.4, R44.1, U3.7
SDA4: J25.3, J26.3, J27.3, J30.4, R58.1, U5.7
SDA5: J31.3, J32.3, J33.3, J36.4, R72.1, U6.7
SDA6: J37.3, J38.3, J39.3, J42.4, R86.1, U7.7
SDA7: J43.3, J44.3, J45.3, J48.4, R100.1, U8.7
SDA8: J49.3, J50.3, J51.3, J54.4, R114.1, U9.7
SDA9: J55.3, J56.3, J57.3, J60.4, R128.1, U10.7
SDA10: J61.3, J62.3, J63.3, J66.4, R142.1, U11.7
SDA11: J67.3, J68.3, J69.3, J72.4, R156.1, U12.7
SDA12: J73.3, J74.3, J75.3, J78.4, R170.1, U13.7
SDA13: J79.3, J80.3, J81.3, J84.4, R184.1, U14.7
SDA_PU1: JP9.3, R6.2
SDA_PU2: JP17.3, R16.2
SDA_PU3: JP27.3, R30.2
SDA_PU4: JP37.3, R44.2
SDA_PU5: JP47.3, R58.2
SDA_PU6: JP57.3, R72.2
SDA_PU7: JP67.3, R86.2
SDA_PU8: JP77.3, R100.2
SDA_PU9: JP87.3, R114.2
SDA_PU10: JP97.3, R128.2
SDA_PU11: JP107.3, R142.2
SDA_PU12: JP117.3, R156.2
SDA_PU13: JP127.3, R170.2
SDA_PU14: JP137.3, R184.2
SWITCH: R1.2, SW1.3, U4.10
SWITCH1: R18.2, SW2.3, U1.10
SWITCH2: R32.2, SW3.3, U2.10
SWITCH3: R46.2, SW4.3, U3.10
SWITCH4: R60.2, SW5.3, U5.10
SWITCH5: R74.2, SW6.3, U6.10
SWITCH6: R88.2, SW7.3, U7.10
SWITCH7: R102.2, SW8.3, U8.10
SWITCH8: R116.2, SW9.3, U9.10
SWITCH9: R130.2, SW10.3, U10.10
SWITCH10: R144.2, SW11.3, U11.10
SWITCH11: R158.2, SW12.3, U12.10
SWITCH12: R172.2, SW13.3, U13.10
SWITCH13: R186.2, SW14.3, U14.10

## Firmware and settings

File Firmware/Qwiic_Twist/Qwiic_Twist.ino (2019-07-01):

/*
  An I2C based Rotary Encoder
  By: Nathan Seidle
  SparkFun Electronics
  Date: October 27th, 2018
  License: This code is public domain but you buy me a beer if you use this and we meet someday (Beerware license).

  Qwiic Twist is an I2C based rotary encoder that tracks how much the dial has been turned.
  It also offers RGB control of the illumination of the encoder (on applicable models).

  For example, if you Wire.request(0x3F, 2) you'll get two bytes from Qwiic Twist and they might read:
  byte 0: 0x01 - The MSB of a 16-bit signed integer
  byte 1: 0x5A - The LSB of a 16-bit signed integer

  0x015A = 346 so the rotary dial has been turned 346 'ticks' since power on

  The Qwiic Twist is best used with the Arduino library found here: http://librarymanager/All#SparkFun_Twist

  Feel like supporting our work? Buy a board from SparkFun!
  https://www.sparkfun.com/products/15083

  To install support for ATtiny84 in Arduino IDE: https://github.com/SpenceKonde/ATTinyCore/blob/master/Installation.md
  This core is installed from the Board Manager menu
  This core has built in support for I2C S/M and serial
  If you have Dave Mellis' ATtiny installed you may need to remove it from \Users\xx\AppData\Local\Arduino15\Packages

  To support 400kHz I2C communication reliably ATtiny84 needs to run at 8MHz. This requires user to
  click on 'Burn Bootloader' before code is loaded.

  version 1.1:
    Change the way the interrupt pin goes low. Fixes issue: https://forum.sparkfun.com/viewtopic.php?f=14&t=49095
  version 1.2: (Brian Schmalz, May 27th, 2019)
    Added Rotation Limit parameter into memory map. If this value is non-zero, then the Encoder Count will never go
      above this value, and will never go below 0. For example, if you have a 360 count encoder, and you set
      Rotation Limit to 359, then you will only get Encoder Count values from 0 to 359 no matter how many rotations
      the encode actually goes through. Note that Rotation Limit can only go from 0 to 32767, and at 0 (default value)
      the feature is disabled and thus v1.2 works just like v1.1.
*/

#include <Wire.h>
#include <EEPROM.h>
#include "nvm.h"

#include "PinChangeInterrupt.h" //Nico Hood's library: https://github.com/NicoHood/PinChangeInterrupt/
//Used for pin change interrupts on ATtinys (encoder button causes interrupt)
//Note: To make this code work with Nico's library you have to comment out https://github.com/NicoHood/PinChangeInterrupt/blob/master/src/PinChangeInterruptSettings.h#L228

#include <avr/sleep.h> //Needed for sleep_mode
#include <avr/power.h> //Needed for powering down perihperals such as the ADC/TWI and Timers

#if defined(__AVR_ATmega328P__)
//Hardware connections while developing with an Uno
const byte addressPin = 6;
const byte ledRedPin = 9; //PWM
const byte ledGreenPin = 10; //PWM
const byte ledBluePin = 5; //PWM
const byte switchPin = 4;
const byte encoderBPin = 3; //Encoder must be on 2/3 on Uno
const byte encoderAPin = 2;
const byte interruptPin = 7; //Pin goes low when a button event is available

#elif defined(__AVR_ATtiny84__)
//Hardware connections for the final design
const byte addressPin = 9;
const byte ledRedPin = 8; //PWM
const byte ledGreenPin = 7; //PWM
const byte ledBluePin = 5; //PWM
const byte switchPin = 3;
const byte encoderBPin = 2;
const byte encoderAPin = 10;
const byte interruptPin = 0;
#endif

//Global variables
//-=-=-=-=-=-=-=-=-=-=-=-=-=-=-=-=-=-=-=-=-=-=-=-=-=-=-=-=-=-=-=-=-=-=-=-=-=-=-=-=-=-=-=-=-=-
//Variables used in the I2C interrupt so we use volatile

//This is the pseudo register map of the product. If user asks for 0x02 then get the 3rd
//byte inside the register map.
//5602/118 on ATtiny84 prior to conversion
//Approximately 4276/156 on ATtiny84 after conversion
struct memoryMap {
  byte id;
  byte status;
  byte firmwareMajor;
  byte firmwareMinor;
  byte interruptEnable;
  int16_t encoderCount;
  int16_t encoderDifference;
  uint16_t timeSinceLastMovement;
  uint16_t timeSinceLastButton;
  byte ledBrightnessRed;
  byte ledBrightnessGreen;
  byte ledBrightnessBlue;
  int16_t ledConnectRed;
  int16_t ledConnectGreen;
  int16_t ledConnectBlue;
  uint16_t turnInterruptTimeout;
  byte i2cAddress;
  uint16_t rotationLimit;
};

const byte statusButtonClickedBit = 2;
const byte statusButtonPressedBit = 1;
const byte statusEncoderMovedBit = 0;

const byte enableInterruptButtonBit = 1;
const byte enableInterruptEncoderBit = 0;

//These are the defaults for all settings
volatile memoryMap registerMap = {
  .id =                         0x5C, // 0x00  
  .status =                     0x00, // 0x01         2 - button clicked, 1 - button pressed, 0 - encoder moved
  .firmwareMajor =              0x01, // 0x02         Firmware version. Helpful for tech support.
  .firmwareMinor =              0x02, // 0x03
  .interruptEnable =            0x03, // 0x04         1 - button interrupt, 0 - encoder interrupt
  .encoderCount =             0x0000, // 0x05, 0x06
  .encoderDifference =        0x0000, // 0x07, 0x08
  .timeSinceLastMovement =    0x0000, // 0x09, 0x0A
  .timeSinceLastButton =      0x0000, // 0x0B, 0x0C
  .ledBrightnessRed =           0xFF, // 0x0D
  .ledBrightnessGreen =         0xFF, // 0x0E
  .ledBrightnessBlue =          0xFF, // 0x0F
  .ledConnectRed =            0x0000, // 0x10, 0x11
  .ledConnectGreen =          0x0000, // 0x12, 0x13
  .ledConnectBlue =           0x0000, // 0x14, 0x15
  .turnInterruptTimeout =        250, // 0x16, 0x17
  .i2cAddress =  I2C_ADDRESS_DEFAULT, // 0x18
  .rotationLimit =                 0, // 0x19, 0x1A   0 means disable this feature (disabled by default)
};

//This defines which of the registers are read-only (0) vs read-write (1)
memoryMap protectionMap = {
  .id = 0x00,
  .status = (1 << statusButtonClickedBit) | (1 << statusEncoderMovedBit), //2 - button clicked, 1 - button pressed, 0 - encoder moved
  .firmwareMajor = 0x00,
  .firmwareMinor = 0x00,
  .interruptEnable = (1 << enableInterruptButtonBit) | (1 << enableInterruptEncoderBit), //1 - button int enable, 0 - encoder int enable
  .encoderCount = (int16_t)0xFFFF,
  .encoderDifference = (int16_t)0xFFFF,
  .timeSinceLastMovement = (uint16_t)0xFFFF,
  .timeSinceLastButton = (uint16_t)0xFFFF,
  .ledBrightnessRed = 0xFF,
  .ledBrightnessGreen = 0xFF,
  .ledBrightnessBlue = 0xFF,
  .ledConnectRed = (int16_t)0xFFFF,
  .ledConnectGreen = (int16_t)0xFFFF,
  .ledConnectBlue = (int16_t)0xFFFF,
  .turnInterruptTimeout = (uint16_t)0xFFFF,
  .i2cAddress = 0xFF,
  .rotationLimit = 0xFFFF,
};

//Cast 32bit address of the object registerMap with uint8_t so we can increment the pointer
uint8_t *registerPointer = (uint8_t *)&registerMap;
uint8_t *protectionPointer = (uint8_t *)&protectionMap;

volatile byte registerNumber; //Gets set when user writes an address. We then serve the spot the user requested.

volatile boolean updateOutputs = false; //Goes true when we receive new bytes from user. Causes LEDs and things to update in main loop.

volatile byte lastEncoded = 0; //Used to compare encoder readings between interrupts. Helps detect turn direction.

volatile unsigned long lastButtonTime; //Time stamp of last button event

volatile unsigned long lastEncoderTwistTime; //Time stamp of last knob movement

//Interrupt turns on when encoder is moved or button is pressed,
//turns off when interrupts are cleared by command
enum State {
  STATE_ENCODER_INT = 0,
  STATE_BUTTON_INT,
  STATE_INT_CLEARED,
  STATE_INT_INDICATED,
};
volatile byte interruptState = STATE_INT_CLEARED;


//-=-=-=-=-=-=-=-=-=-=-=-=-=-=-=-=-=-=-=-=-=-=-=-=-=-=-=-=-=-=-=-=-=-=-=-=-=-=-=-=-=-=-=-=-=-

void setup(void)
{
  pinMode(addressPin, INPUT_PULLUP);
  pinMode(ledRedPin, OUTPUT);
  pinMode(ledGreenPin, OUTPUT);
  pinMode(ledBluePin, OUTPUT);
  pinMode(switchPin, INPUT); //No pull-up. It's pulled low with 10k
  pinMode(encoderBPin, INPUT); //No pull-up. External 10k
  pinMode(encoderAPin, INPUT); //No pull-up. External 10k
  pinMode(interruptPin, INPUT); //Interrupt is high-impedance until we have int (and then go low). Pulled high with 10k with cuttable jumper.

#if defined(__AVR_ATmega328P__)
  pinMode(addressPin, INPUT_PULLUP);
  pinMode(ledRedPin, OUTPUT);
  pinMode(ledGreenPin, OUTPUT);
  pinMode(ledBluePin, OUTPUT);
  pinMode(switchPin, INPUT); //No pull-up. It's pulled low with 10k
  pinMode(encoderBPin, INPUT_PULLUP);
  pinMode(encoderAPin, INPUT_PULLUP);
  pinMode(interruptPin, INPUT); //Interrupt is high-impedance until we have int (and then go low). Optional external pull up.
#endif

  turnOffExtraBits(); //Turn off all unused peripherals

  readSystemSettings(); //Load all system settings from EEPROM

  setupInterrupts(); //Enable pin change interrupts for I2C, encoder, switch, etc

  lastEncoderTwistTime = 0; //User has not yet twisted the encoder. Used for firing int pin.
  lastButtonTime = 0; //User has not yet pressed the encoder button.

  startI2C(); //Determine the I2C address we should be using and begin listening on I2C bus

#if defined(__AVR_ATmega328P__)
  Serial.begin(9600);
  Serial.println("Qwiic Twist");
  Serial.print("Address: 0x");

  if (digitalRead(addressPin) == HIGH) //Default is HIGH, the address jumper is open
    Serial.print(registerMap.i2cAddress, HEX);
  else
    Serial.print(I2C_FORCED_ADDRESS, HEX);
  Serial.println();

#endif
}

void loop(void)
{
  //Interrupt pin state machine
  //There are four states: Encoder Int, Button Int, Int Cleared, Int Indicated
  //ENCODER_INT state is set here once user has stopped turning encoder
  //BUTTON_INT state is set if user presses button
  //INT_CLEARED state is set in the I2C interrupt when Clear Ints command is received.
  //INT_INDICATED state is set once we change the INT pin to go low
  if (interruptState == STATE_INT_CLEARED)
  {
    //See if user has turned the encoder
    if ( registerMap.status & (1 << statusEncoderMovedBit) )
    {
      //Check if encoder interrupt is enabled
      if ( (registerMap.interruptEnable & (1 << enableInterruptEncoderBit) ) )
      {
        //See if enough time has passed since the user has stopped turning the encoder
        if ( (millis() - lastEncoderTwistTime) > registerMap.turnInterruptTimeout)
        {
          interruptState = STATE_ENCODER_INT; //Go to next state
        }
      }
    }
  }

  //If we are in either encoder or button interrupt state, then set INT low
  if(interruptState == STATE_ENCODER_INT || interruptState == STATE_BUTTON_INT)
  {
    //Set the interrupt pin low to indicate interrupt
    pinMode(interruptPin, OUTPUT);
    digitalWrite(interruptPin, LOW);
    interruptState = STATE_INT_INDICATED;
  }

  if (updateOutputs == true)
  {
    updateOutputs = false;

    //Record anything new to EEPROM like connection values and LED values
    //It can take ~3.4ms to write EEPROM byte so we do that here instead of in interrupt
    recordSystemSettings();
  }

#if defined(__AVR_ATmega328P__)
  Serial.print("Encoder: ");
  Serial.print(registerMap.encoderCount);

  Serial.print(" Red: ");
  Serial.print(registerMap.ledBrightnessRed);

  Serial.print(" Blue: ");
  Serial.print(registerMap.ledBrightnessBlue);

  Serial.print(" Diff: ");
  Serial.print(registerMap.encoderDifference);

  Serial.print(" Reg: ");
  Serial.print(registerNumber);

  if (registerMap.status & (1 << statusButtonClickedBit) )
    Serial.print(" Click");

  Serial.println();
#endif

  sleep_mode(); //Stop everything and go to sleep. Wake up from Encoder, Button, or I2C interrupts.
}

//If the current setting is different from that in EEPROM, update EEPROM
void recordSystemSettings(void)
{
  //I2C address is byte
  byte i2cAddr;

  //Error check the current I2C address
  if (registerMap.i2cAddress < 0x08 || registerMap.i2cAddress > 0x77)
  {
    //User has set the address out of range
    //Go back to defaults
    registerMap.i2cAddress = I2C_ADDRESS_DEFAULT;
  }

  //Read the value currently in EEPROM. If it's different from the memory map then record the memory map value to EEPROM.
  EEPROM.get(LOCATION_I2C_ADDRESS, i2cAddr);
  if (i2cAddr != registerMap.i2cAddress)
  {
    EEPROM.put(LOCATION_I2C_ADDRESS, (byte)registerMap.i2cAddress);
    startI2C(); //Determine the I2C address we should be using and begin listening on I2C bus
  }

  byte intBits;
  EEPROM.get(LOCATION_INTERRUPTS, intBits);
  if (intBits != registerMap.interruptEnable)
    EEPROM.put(LOCATION_INTERRUPTS, (byte)registerMap.interruptEnable);

  //LED values are bytes
  byte ledBrightness;

  EEPROM.get(LOCATION_RED_BRIGHTNESS, ledBrightness);
  if (ledBrightness != registerMap.ledBrightnessRed)
    EEPROM.put(LOCATION_RED_BRIGHTNESS, (byte)registerMap.ledBrightnessRed);
  analogWrite(ledRedPin, 255 - registerMap.ledBrightnessRed); //Change LED brightness

  EEPROM.get(LOCATION_GREEN_BRIGHTNESS, ledBrightness);
  if (ledBrightness != registerMap.ledBrightnessGreen)
    EEPROM.put(LOCATION_GREEN_BRIGHTNESS, (byte)registerMap.ledBrightnessGreen);
  analogWrite(ledGreenPin, 255 - registerMap.ledBrightnessGreen); //Change LED brightness

  EEPROM.get(LOCATION_BLUE_BRIGHTNESS, ledBrightness);
  if (ledBrightness != registerMap.ledBrightnessBlue)
    EEPROM.put(LOCATION_BLUE_BRIGHTNESS, (byte)registerMap.ledBrightnessBlue);
  analogWrite(ledBluePin, 255 - registerMap.ledBrightnessBlue); //Change LED brightness

  //Connect amounts are ints
  int16_t setting;

  EEPROM.get(LOCATION_RED_CONNECT_AMOUNT, setting);
  if (setting != registerMap.ledConnectRed)
    EEPROM.put(LOCATION_RED_CONNECT_AMOUNT, (int16_t)registerMap.ledConnectRed);

  EEPROM.get(LOCATION_GREEN_CONNECT_AMOUNT, setting);
  if (setting != registerMap.ledConnectGreen)
    EEPROM.put(LOCATION_GREEN_CONNECT_AMOUNT, (int16_t)registerMap.ledConnectGreen);

  EEPROM.get(LOCATION_BLUE_CONNECT_AMOUNT, setting);
  if (setting != registerMap.ledConnectBlue)
    EEPROM.put(LOCATION_BLUE_CONNECT_AMOUNT, (int16_t)registerMap.ledConnectBlue);

  //Turn Timeout is uint16_t
  uint16_t timeout;

  EEPROM.get(LOCATION_TURN_INTERRUPT_TIMEOUT_AMOUNT, timeout);
  if (timeout != registerMap.turnInterruptTimeout)
    EEPROM.put(LOCATION_TURN_INTERRUPT_TIMEOUT_AMOUNT, (int16_t)registerMap.turnInterruptTimeout);

  //If the user has zero'd out the timestamps then reflect that in the globals
  if (registerMap.timeSinceLastMovement == 0) lastEncoderTwistTime = 0;
  if (registerMap.timeSinceLastButton == 0) lastButtonTime = 0;

  //Rotation Limit is uint16_t
  uint16_t rotationLim;

  EEPROM.get(LOCATION_ROTATION_LIMIT, rotationLim);
  if (rotationLim != registerMap.rotationLimit)
    EEPROM.put(LOCATION_ROTATION_LIMIT, (int16_t)registerMap.rotationLimit);
}

//Reads the current system settings from EEPROM
//If anything looks weird, reset setting to default value
void readSystemSettings(void)
{
  uint16_t discard; // do-nothing variable put in to eleminate compiler warnings

  //Read what I2C address we should use
  registerMap.i2cAddress = EEPROM.read(LOCATION_I2C_ADDRESS);
  if (registerMap.i2cAddress == 0xFF) //Blank
  {
    registerMap.i2cAddress = I2C_ADDRESS_DEFAULT; //By default, we listen for I2C_ADDRESS_DEFAULT
    EEPROM.write(LOCATION_I2C_ADDRESS, registerMap.i2cAddress);
  }

  //Error check I2C address we read from EEPROM
  if (registerMap.i2cAddress < 0x08 || registerMap.i2cAddress > 0x77)
  {
    //User has set the address out of range
    //Go back to defaults
    registerMap.i2cAddress = I2C_ADDRESS_DEFAULT;
    EEPROM.write(LOCATION_I2C_ADDRESS, registerMap.i2cAddress);
  }

  //Read the interrupt bits
  registerMap.interruptEnable = EEPROM.read(LOCATION_INTERRUPTS);
  if (registerMap.interruptEnable == 0xFF) //Blank
  {
    registerMap.interruptEnable = 0x03; //By default, enable the click and encoder interrupts
    EEPROM.write(LOCATION_INTERRUPTS, registerMap.interruptEnable);
  }

  //Read the starting value for the red LED
  registerMap.ledBrightnessRed = EEPROM.read(LOCATION_RED_BRIGHTNESS);
  analogWrite(ledRedPin, 255 - registerMap.ledBrightnessRed);

  //Read the starting value for the green LED
  registerMap.ledBrightnessGreen = EEPROM.read(LOCATION_GREEN_BRIGHTNESS);
  analogWrite(ledGreenPin, 255 - registerMap.ledBrightnessGreen);

  //Read the starting value for the blue LED
  registerMap.ledBrightnessBlue = EEPROM.read(LOCATION_BLUE_BRIGHTNESS);
  analogWrite(ledBluePin, 255 - registerMap.ledBrightnessBlue);

  //Read the connection value for red color
  //There are 24 pulses per rotation on the encoder
  //For each pulse, how much does the user want red to go up (or down)
  discard = EEPROM.get(LOCATION_RED_CONNECT_AMOUNT, registerMap.ledConnectRed); //16-bit
  if ((uint16_t)registerMap.ledConnectRed == 0xFFFF) //Blank
  {
    registerMap.ledConnectRed = 0; //Default to no connection
    EEPROM.put(LOCATION_RED_CONNECT_AMOUNT, (int16_t)registerMap.ledConnectRed);
  }

  discard = EEPROM.get(LOCATION_GREEN_CONNECT_AMOUNT, registerMap.ledConnectGreen);
  if ((uint16_t)registerMap.ledConnectGreen == 0xFFFF)
  {
    registerMap.ledConnectGreen = 0; //Default to no connection
    EEPROM.put(LOCATION_GREEN_CONNECT_AMOUNT, (int16_t)registerMap.ledConnectGreen);
  }

  discard = EEPROM.get(LOCATION_BLUE_CONNECT_AMOUNT, registerMap.ledConnectBlue);
  if ((uint16_t)registerMap.ledConnectBlue == 0xFFFF)
  {
    registerMap.ledConnectBlue = 0; //Default to no connection
    EEPROM.put(LOCATION_BLUE_CONNECT_AMOUNT, (int16_t)registerMap.ledConnectBlue);
  }

  discard = EEPROM.get(LOCATION_TURN_INTERRUPT_TIMEOUT_AMOUNT, registerMap.turnInterruptTimeout);
  if ((uint16_t)registerMap.turnInterruptTimeout == 0xFFFF)
  {
    registerMap.turnInterruptTimeout = 250; //Default to 250ms
    EEPROM.put(LOCATION_TURN_INTERRUPT_TIMEOUT_AMOUNT, (int16_t)registerMap.turnInterruptTimeout);
  }

  discard = EEPROM.get(LOCATION_ROTATION_LIMIT, registerMap.rotationLimit);
  if ((uint16_t)registerMap.rotationLimit == 0xFFFF)
  {
    registerMap.rotationLimit = 0; // Default to 0 (off)
    EEPROM.put(LOCATION_ROTATION_LIMIT, (int16_t)registerMap.rotationLimit);
  }

  // To eleminate compiler warning
  (void)discard;
}

//Turn off anything we aren't going to use
void turnOffExtraBits()
{
  //Disable ADC
  ADCSRA = 0;

  //Disble Brown-Out Detect
  MCUCR = bit (BODS) | bit (BODSE);
  MCUCR = bit (BODS);

  //Power down various bits of hardware to lower power usage
  //set_sleep_mode(SLEEP_MODE_PWR_DOWN);
  set_sleep_mode(SLEEP_MODE_IDLE);
  sleep_enable();
}

//Begin listening on I2C bus as I2C slave using the global variable setting_i2c_address
void startI2C()
{
  Wire.end(); //Before we can change addresses we need to stop

  if (digitalRead(addressPin) == HIGH) //Default is HIGH, the address jumper is open
    Wire.begin(registerMap.i2cAddress); //Start I2C and answer calls using address from EEPROM
  else
    Wire.begin(I2C_FORCED_ADDRESS); //Force address to I2C_FORCED_ADDRESS if user has closed the solder jumper

  //The connections to the interrupts are severed when a Wire.begin occurs. So re-declare them.
  Wire.onReceive(receiveEvent);
  Wire.onRequest(requestEvent);
}

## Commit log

2018-11-13 Increasing panel size for better production.
    [Qwiic Twist-Panel.GBL, Qwiic Twist-Panel.GBO, Qwiic Twist-Panel.GBS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]
2018-12-03 Main firmware works with memory map. Auto-clearing of certain variables does not work.
    [Qwiic Twist-BottomJig.brd, Qwiic Twist-BottomJig.sch, Qwiic Twist-MiddleJig.brd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]
2018-12-04 Add I2C address error checking.
    [Qwiic_Twist.ino]
2018-12-04 Removing old files
    [Qwiic Twist-BottomJig.GBL, Qwiic Twist-BottomJig.GBO, Qwiic Twist-BottomJig.GBS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]
2019-01-24 Changing interrupt control to a state machine
    This reduces the amount of int pin toggling as seen in this issue: https://forum.sparkfun.com/viewtopic.php?f=14&t=49095
    [Qwiic Twist.brd]
2019-04-28 Adding dimensions to board
    [Qwiic Twist.brd]
2019-05-20 Adding ignore. Fix I2C addresses in schematic. Add dims and new sch pdfs.
    [Qwiic Twist.brd, Qwiic Twist.sch]
2019-05-27 Added new feature: New register called Rotation Limit. If set to non-zero value, it will force EncoderCount to 'wrap around' at Rotation Limit, and also prevent EncoderCount from going below zero. Te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
    [Qwiic_Twist.ino]

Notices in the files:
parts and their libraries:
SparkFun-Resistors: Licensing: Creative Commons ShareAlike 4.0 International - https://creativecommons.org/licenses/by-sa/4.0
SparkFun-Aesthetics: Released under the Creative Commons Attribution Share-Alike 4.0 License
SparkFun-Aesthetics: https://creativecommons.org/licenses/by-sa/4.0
